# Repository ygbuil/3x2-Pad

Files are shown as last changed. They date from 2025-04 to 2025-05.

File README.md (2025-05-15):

# 5-Key Keyboard Pad (Pro Micro-Based)

This project is a custom-built 5-key keyboard pad designed and developed entirely from scratch. It’s powered by a **Pro Micro microcontroller** and is fully compatible with **VIA Software**, a powerful configuration tool for custom keyboards.

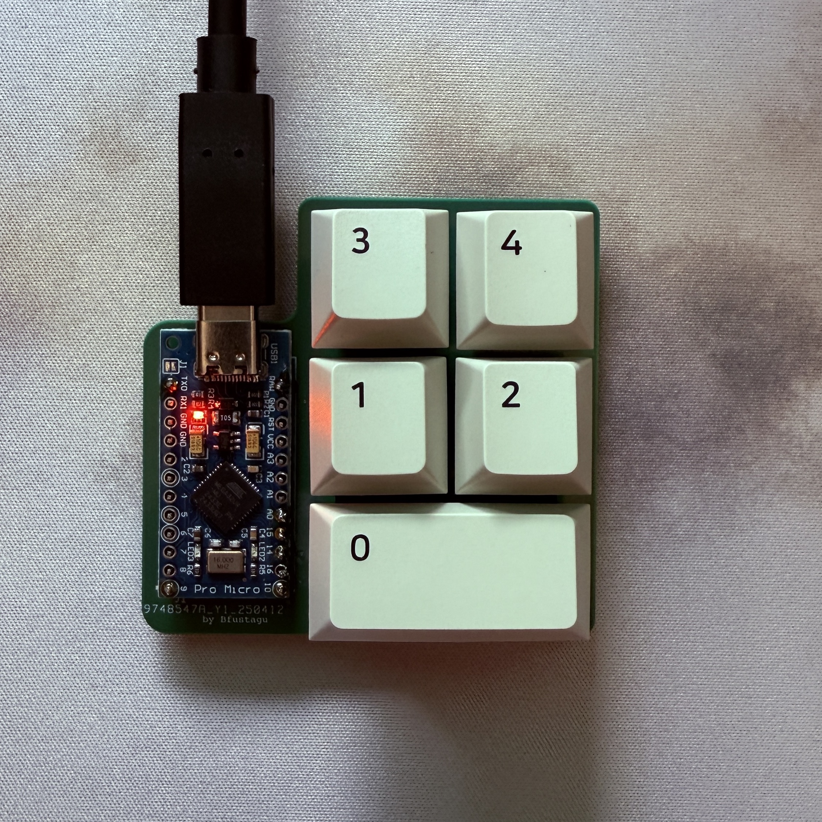
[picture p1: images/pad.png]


## Features

- 5 fully customizable keys using VIA Software.
- Hotswap PCB, allowing for quick swap of Mechanical Switches.

## Project Journey

- **Custom PCB Design**  
  I designed the PCB from the ground up using **KiCad**, an open-source electronics design automation suite. The design files were sent to a professional manufacturer for production.

- **Manual Assembly**  
  Once the PCBs arrived, I soldered all components including diodes, Pro Micro and hotswap sockets.

- **Firmware Development**  
  I created and flashed the keyboard's firmware using **QMK Firmware**, an open source software widely used in the mechanical keyboard community. The keyboard is **VIA-compatible**. [VIA](https://usevia.app) is a user-friendly software that enables real-time keyboard customization through a simple graphical interface, allowing for key remaps, creation of macros, configuration of layers and more, without any coding involved.

## Process photos

Kicad modelling:

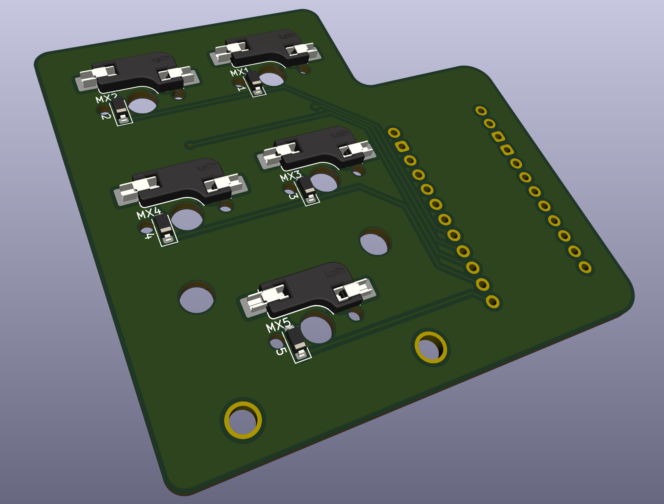
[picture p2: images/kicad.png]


Soldering:

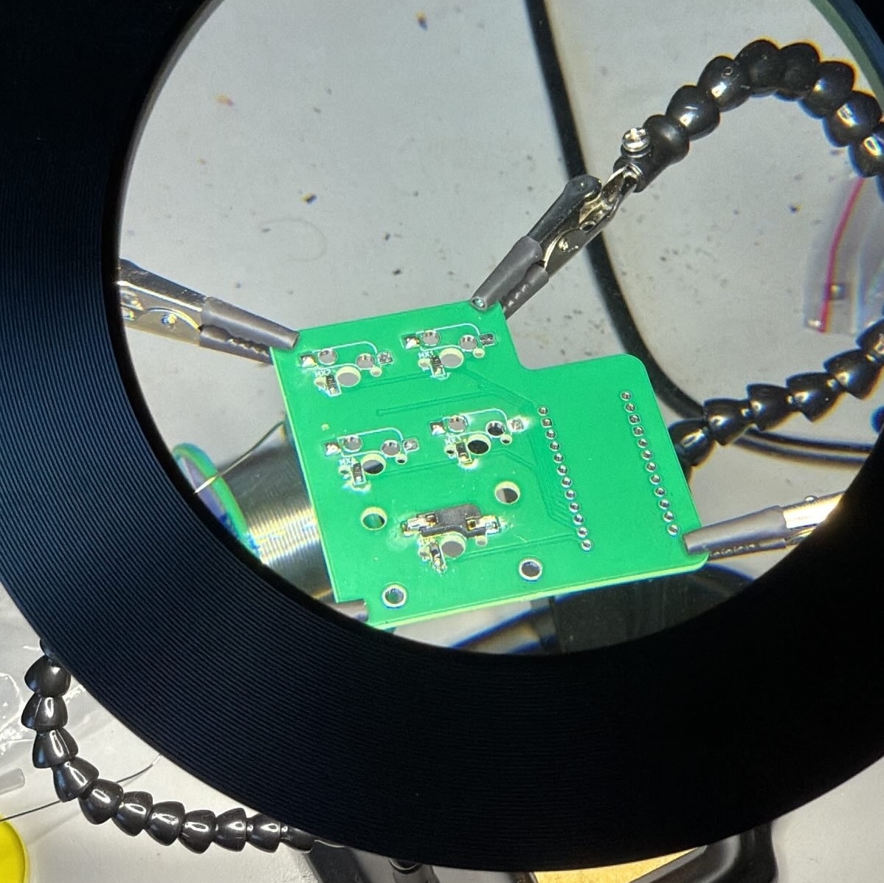
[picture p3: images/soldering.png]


Final product:



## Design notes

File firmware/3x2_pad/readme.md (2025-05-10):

# 3x2_pad

## Create firmware

* Install QMK according to docs.
* Open folder `<local_path>/qmk_firmware` in VSCode.
* Run `qmk new-keyboard`.
    * Choose keyboard name: `3x2_pad` (no spaces and all lower case, this will actually be the keyboard folder name).
    * Choose layout: `None of the above`.
    * Choose MCU: Choose yours.
* Go to `/qmk_firmware/keyboards/3x2_pad/keyboard.json` and:
    * Modify `cols` and `rows` to map the MCU pins to the rows and cols of our schematic: 
        ```json
        "matrix_pins": {
            "cols": ["B1", "B3"],
            "rows": ["F7", "B2", "B6"]
        }
        ```
        <div style="display: flex; gap: 10px;">
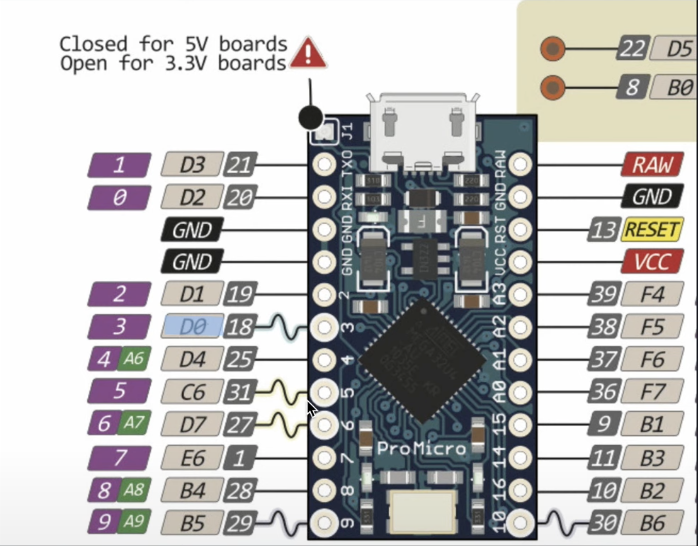
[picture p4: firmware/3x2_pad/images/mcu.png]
MCU
            
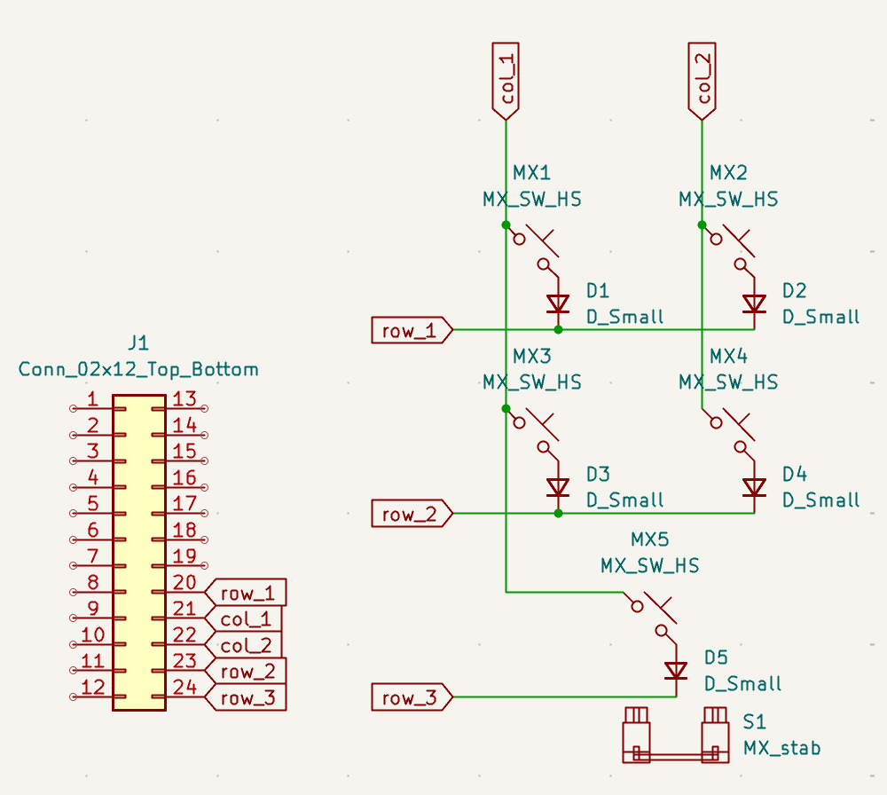
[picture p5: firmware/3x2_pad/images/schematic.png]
Schematic
            
        </div>
    * Modify `pid` (product id) and `vid` (vendor id) to yor likings with the help of a "ascii to hex online convertor".
    * Modify `layout` key:
        * `matrix` represents the key location in the schematic matrix, represented as `[<row>, <col>]`.
        * `x` and `y` are the coordinates in key units (1u, 1.25u, etc) of the top left position of a key, with the origin of coordinates situated at the top left.
        * In case a key is different than `1u`, we need to specify its width `w`.
    
        ```json
        "layout": [
            {"matrix": [0, 0], "x": 0, "y": 0},
            {"matrix": [0, 1], "x": 1, "y": 0},
            {"matrix": [1, 0], "x": 0, "y": 1},
            {"matrix": [1, 1], "x": 1, "y": 1},
            {"matrix": [2, 0], "x": 0, "y": 2, "w": 2}
        ]
        ```
* Create `/qmk_firmware/keyboards/3x2_pad/keymaps/default/rules.mk` with the content: `VIA_ENABLE = yes`.
* Modify `/qmk_firmware/keyboards/3x2_pad/keymaps/default/keymap.c` `LAYOUT` to the desired default layout:
    ```json
    LAYOUT(
        KC_P3,   KC_P4,
        KC_P1,   KC_P2,
        KC_P0
    )
    ```
* In `/qmk_firmware/keyboards/3x2_pad/`, create a `via.json` from scratch as you can see in this repo. The `keymap` key is derived from inputing in the Keyboard Layout Editor the `[<row>, <col>]` (explained before) and extracting the raw data.

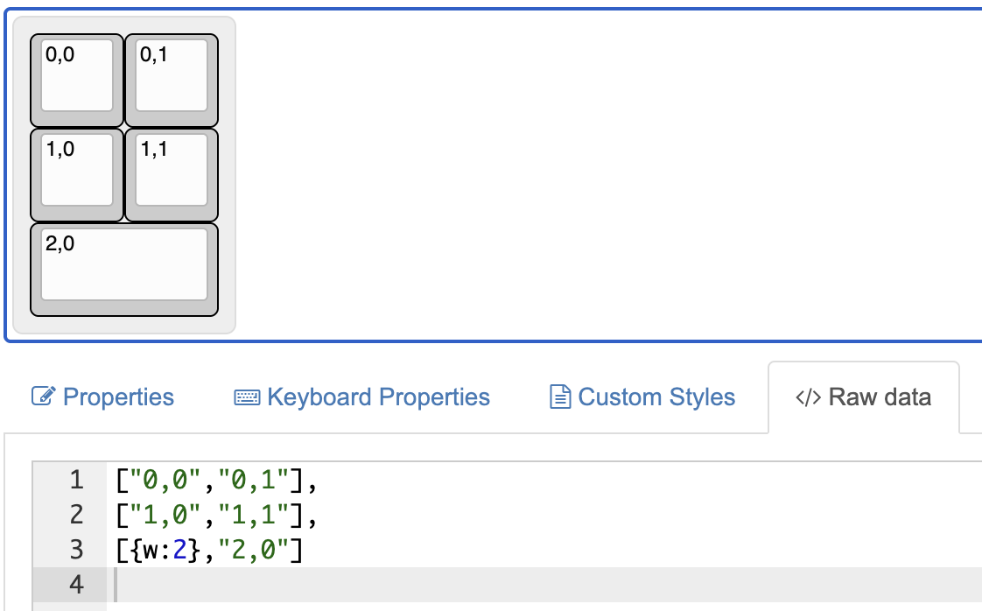
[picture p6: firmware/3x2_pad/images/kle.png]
KLE
    
* Flash the keyboard:
    * Option 1: Run `qmk flash -kb 3x2_pad -km default`. First it will compile a `3x2_pad_default.hex` file in `/qmk_firmware`. Then it will prompt you to enter bootloader mode by closing the circuit for RESET and GND. Once you do it, flashing will start and after that keyboard will be ready to use.

    * Option 2: Run `qmk compile -kb 3x2_pad -km default`. This will compile a `3x2_pad_default.hex` file in `/qmk_firmware`. Download `QMK Toolbox` and open it. Select the compiled `3x2_pad_default.hex`, enter bootloader mode by closing the circuit for RESET and GND, and finally click `flash`.
* To use it with Via, go to design tab and upload `/qmk_firmware/keyboards/3x2_pad/via.json`.

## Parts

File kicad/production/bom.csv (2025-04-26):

Designator | Footprint | Quantity | Value | LCSC Part #
D1, D2, D3, D4, D5 | D_SOD-123 | 5 | D_Small
J1 | ProMicro_USBup | 1 | Conn_02x12_Top_Bottom
MX1, MX2, MX3, MX4, MX5 | SW_MX_HS_CPG151101S11_1u | 5 | MX_SW_HS
S1 | STAB_MX_P_2u | 1 | MX_stab

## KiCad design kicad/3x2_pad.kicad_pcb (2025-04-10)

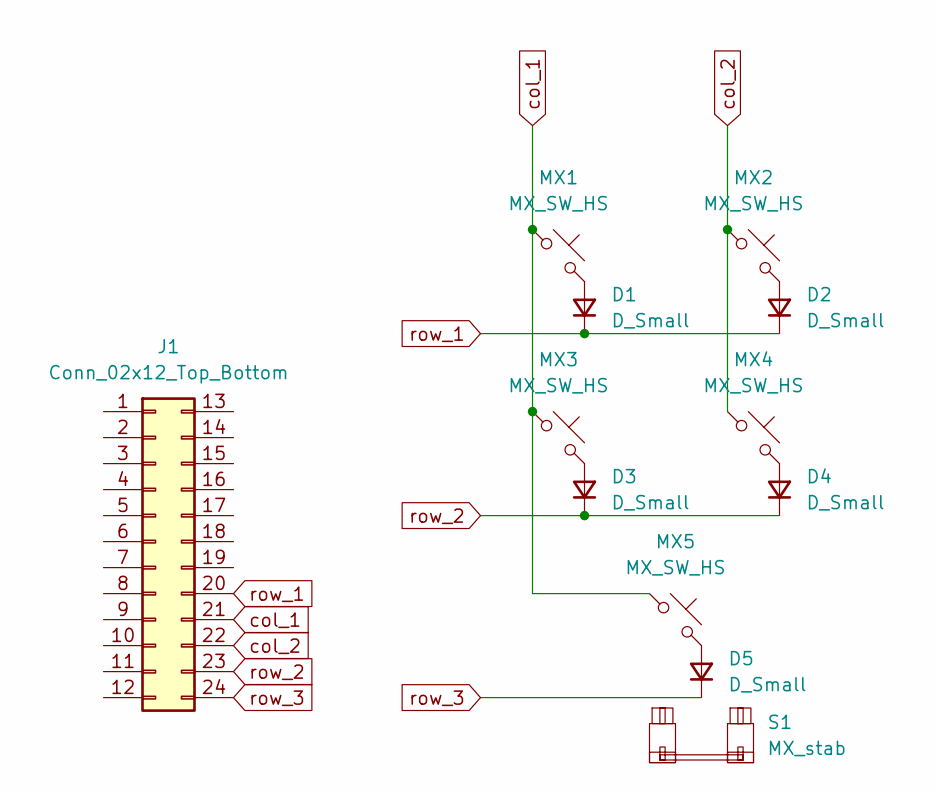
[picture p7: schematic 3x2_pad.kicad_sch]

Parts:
D1, D2, D3, D4, D5: D_Small; D_SOD-123
J1: Conn_02x12_Top_Bottom; ProMicro_USBup
MX1, MX2, MX3, MX4, MX5: MX_SW_HS; SW_MX_HS_CPG151101S11_1u
S1: MX_stab; STAB_MX_P_2u

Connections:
unnamed: D1.2 (A), MX1.2
unnamed: D2.2 (A), MX2.2
unnamed: D3.2 (A), MX3.2
unnamed: D4.2 (A), MX4.2
unnamed: D5.2 (A), MX5.2
col_1: J1.21, MX1.1, MX3.1, MX5.1
col_2: J1.22, MX2.1, MX4.1
row_1: D1.1 (K), D2.1 (K), J1.20
row_2: D3.1 (K), D4.1 (K), J1.23
row_3: D5.1 (K), J1.24

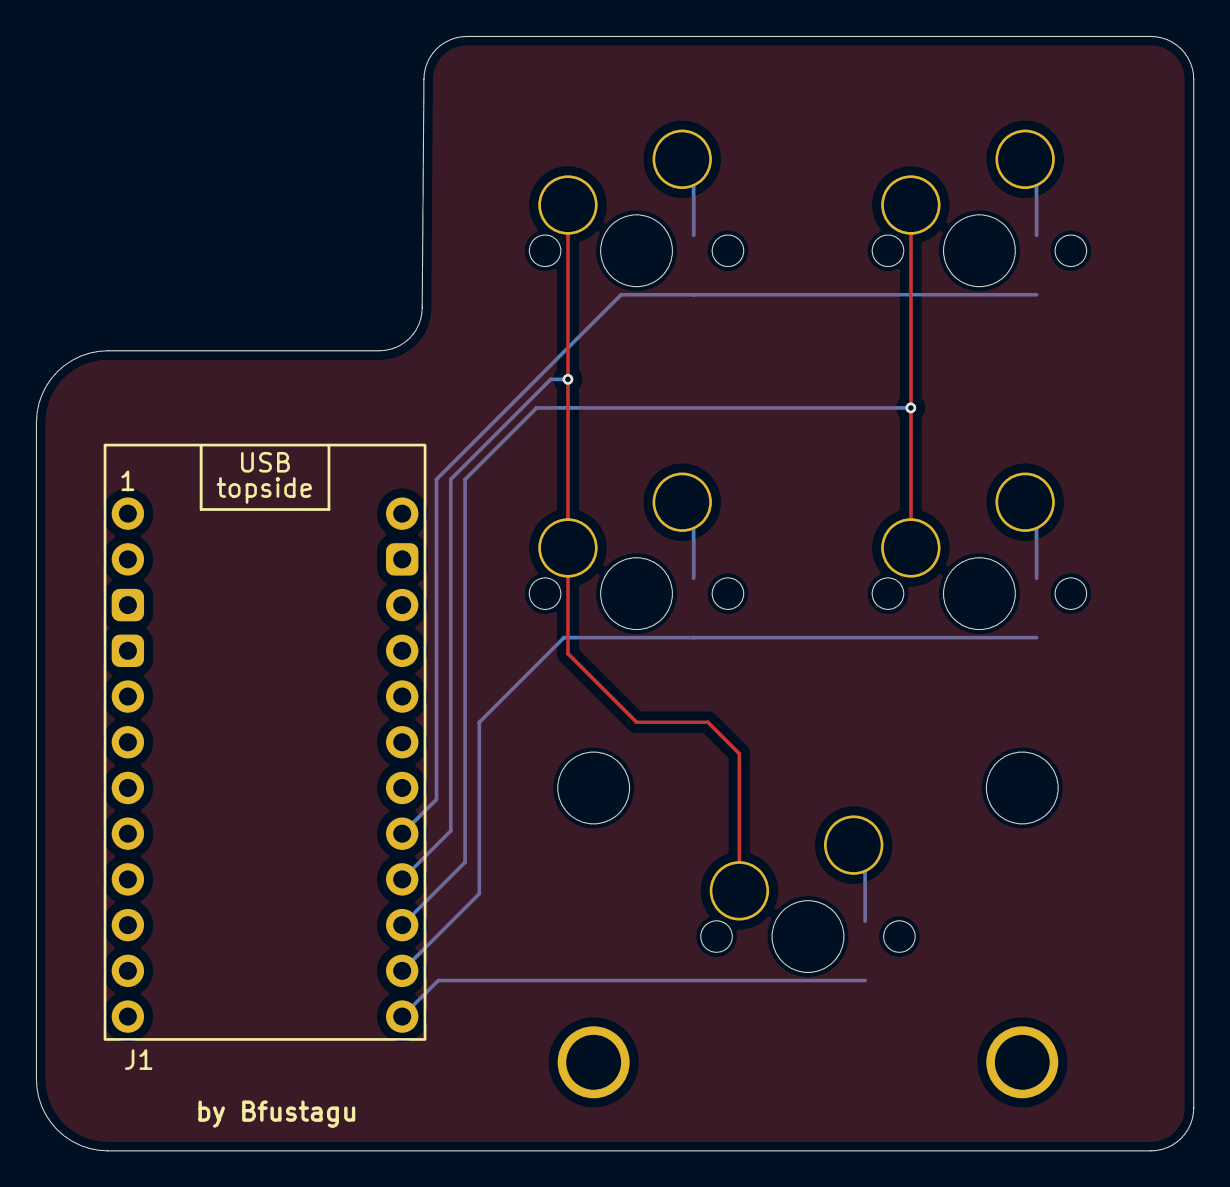
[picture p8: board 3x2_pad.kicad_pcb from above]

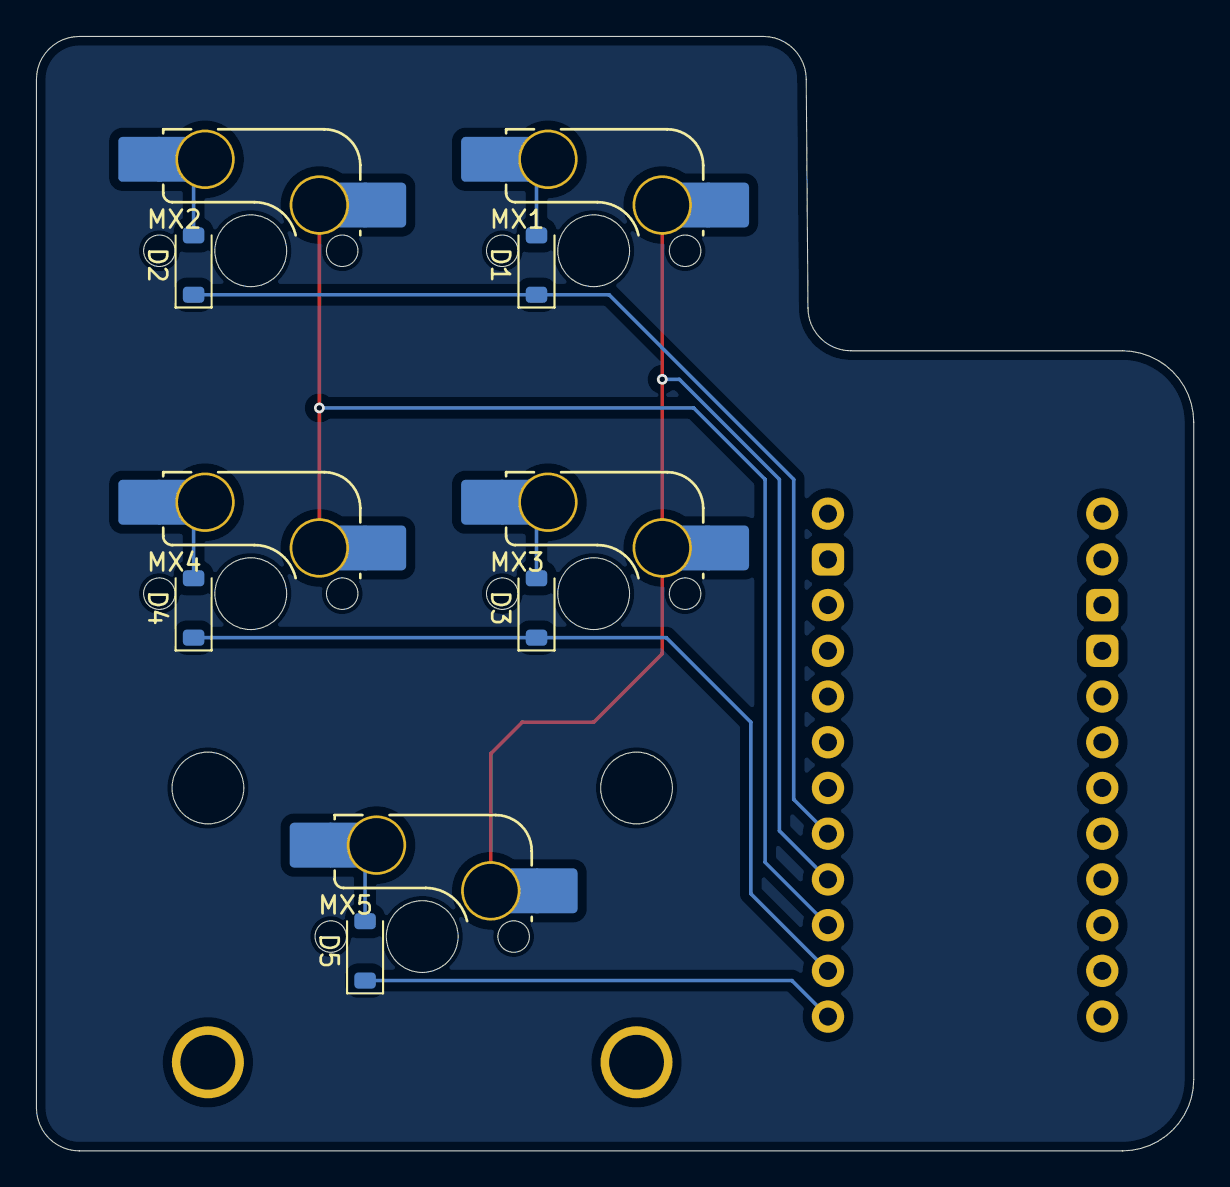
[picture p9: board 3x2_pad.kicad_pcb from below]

Board: 2 copper layers, 64.3 x 61.9 mm, 12 parts (10 on the bottom side), 10 nets.

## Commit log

2025-04-10 fisrt commit
    [3x2_pad.kicad_pcb, 3x2_pad.kicad_sch]
2025-04-26 pcb folder
    [3x2_pad.kicad_pcb, 3x2_pad.kicad_sch, bom.csv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]
